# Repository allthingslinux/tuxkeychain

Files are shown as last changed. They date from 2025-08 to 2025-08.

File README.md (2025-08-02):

# Tux Keychain
Keychain shaped like Tux, the Linux mascot. But it's not just a keychain, it runs embedded Linux!

Unfortunately this is more expensive than usual due to tariffs and inflation. (Probably cheaper in other countries.)

NOTE: This is still in the prototype stage, changes to the design are likely.

## Manufacturing
- This is a 4-layer PCB so it can fit in the Tux keychain form factor.
- Make sure you use ENIG for the PCB finish, else Tux will be gray instead of gold. (If you want a gray Tux, seek help.)
- This is designed for JLCPCBs assembly service, some parts are LCSC exclusive*.

*You can probably find them on other chinese distributors, but I don't know which ones.

## Attribution
The Allwinner F1C100s footprint/symbol is from https://github.com/thirtythreeforty/3340_kicad (F1C100s symbol, QFN-88_EP_10x10_Pitch0.4mm footprint).
Same for the JW5211 symbol and footprint.

Schematic heavily based on the business card design by thirtythreeforty (https://www.thirtythreeforty.net/posts/2019/12/my-business-card-runs-linux/businesscard.pdf).

Tux attribution: [lewing@isc.tamu.edu](https://isc.tamu.edu/~lewing/linux/) (Larry Ewing) and [The GIMP](https://www.gimp.org/).

## Images
> [!NOTE]
> These are auto-generated and will always be up to date (GitHub cache may make them seem out of date)

|PCB|Schematic|
|---|---|
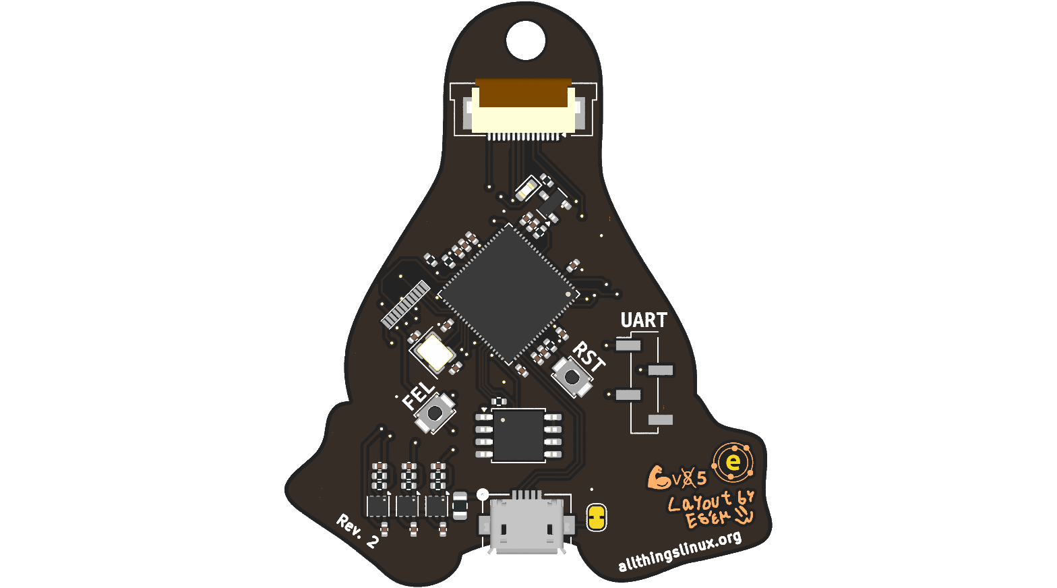
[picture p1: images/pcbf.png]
PCB Front
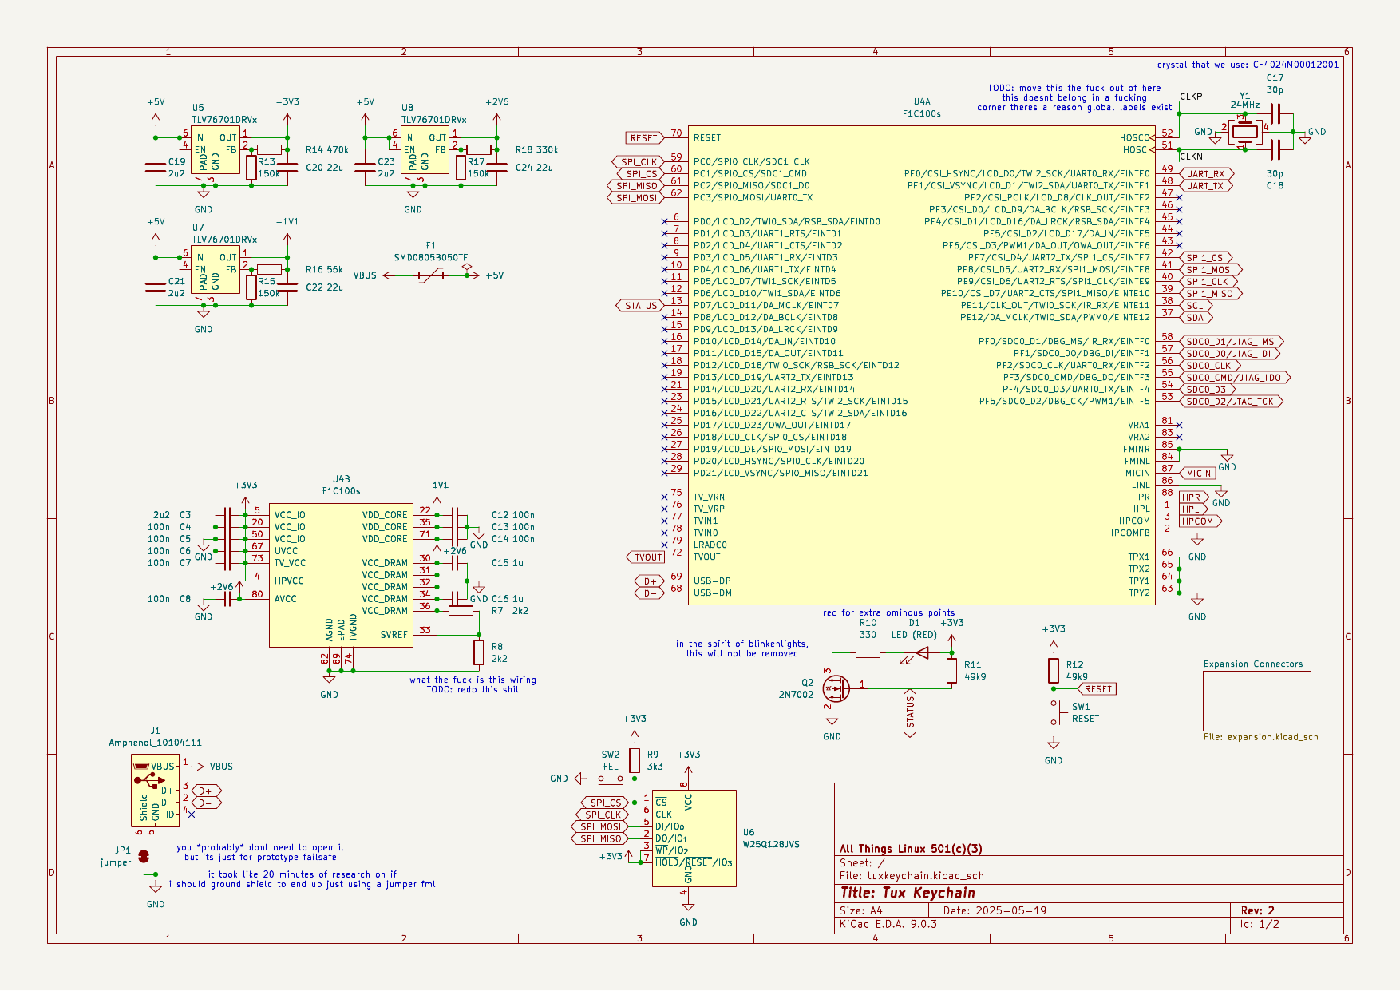
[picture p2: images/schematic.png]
Schematic
|||
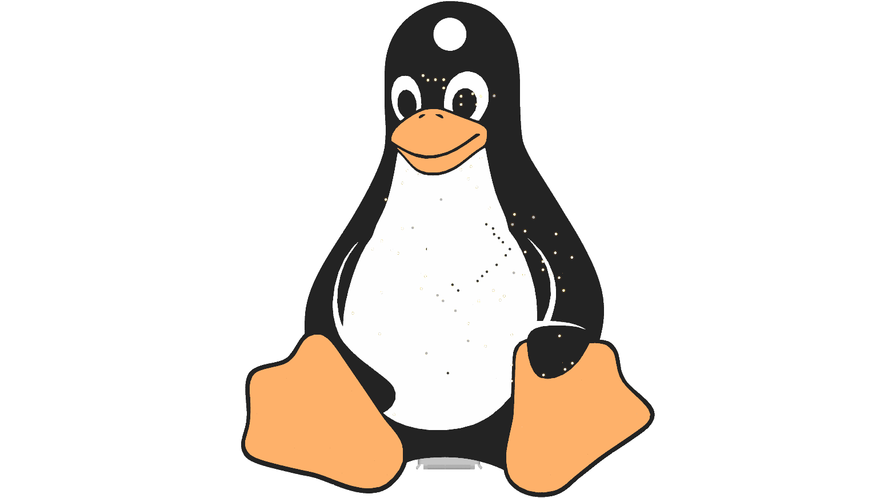
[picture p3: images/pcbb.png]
PCB Back
|||

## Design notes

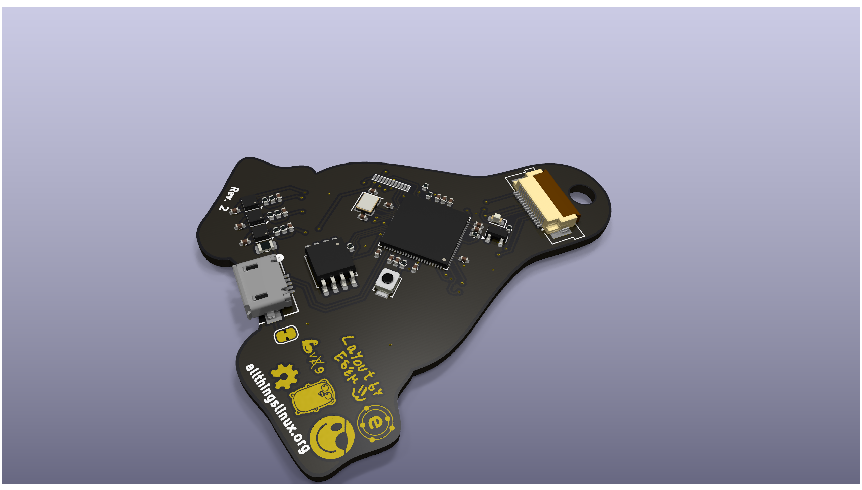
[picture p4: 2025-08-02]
tuxkeychain.png

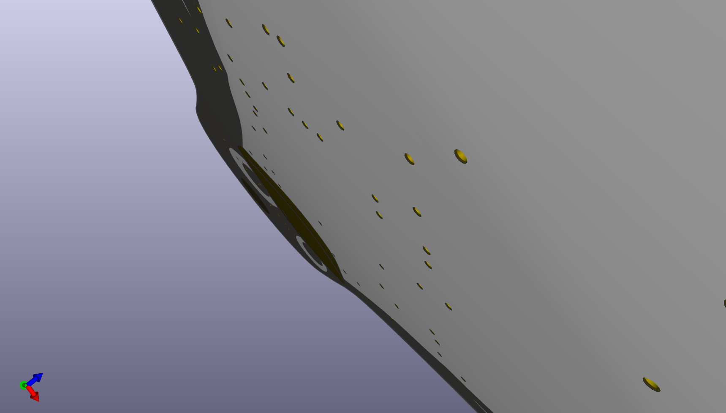
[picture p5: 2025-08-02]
tucks.png

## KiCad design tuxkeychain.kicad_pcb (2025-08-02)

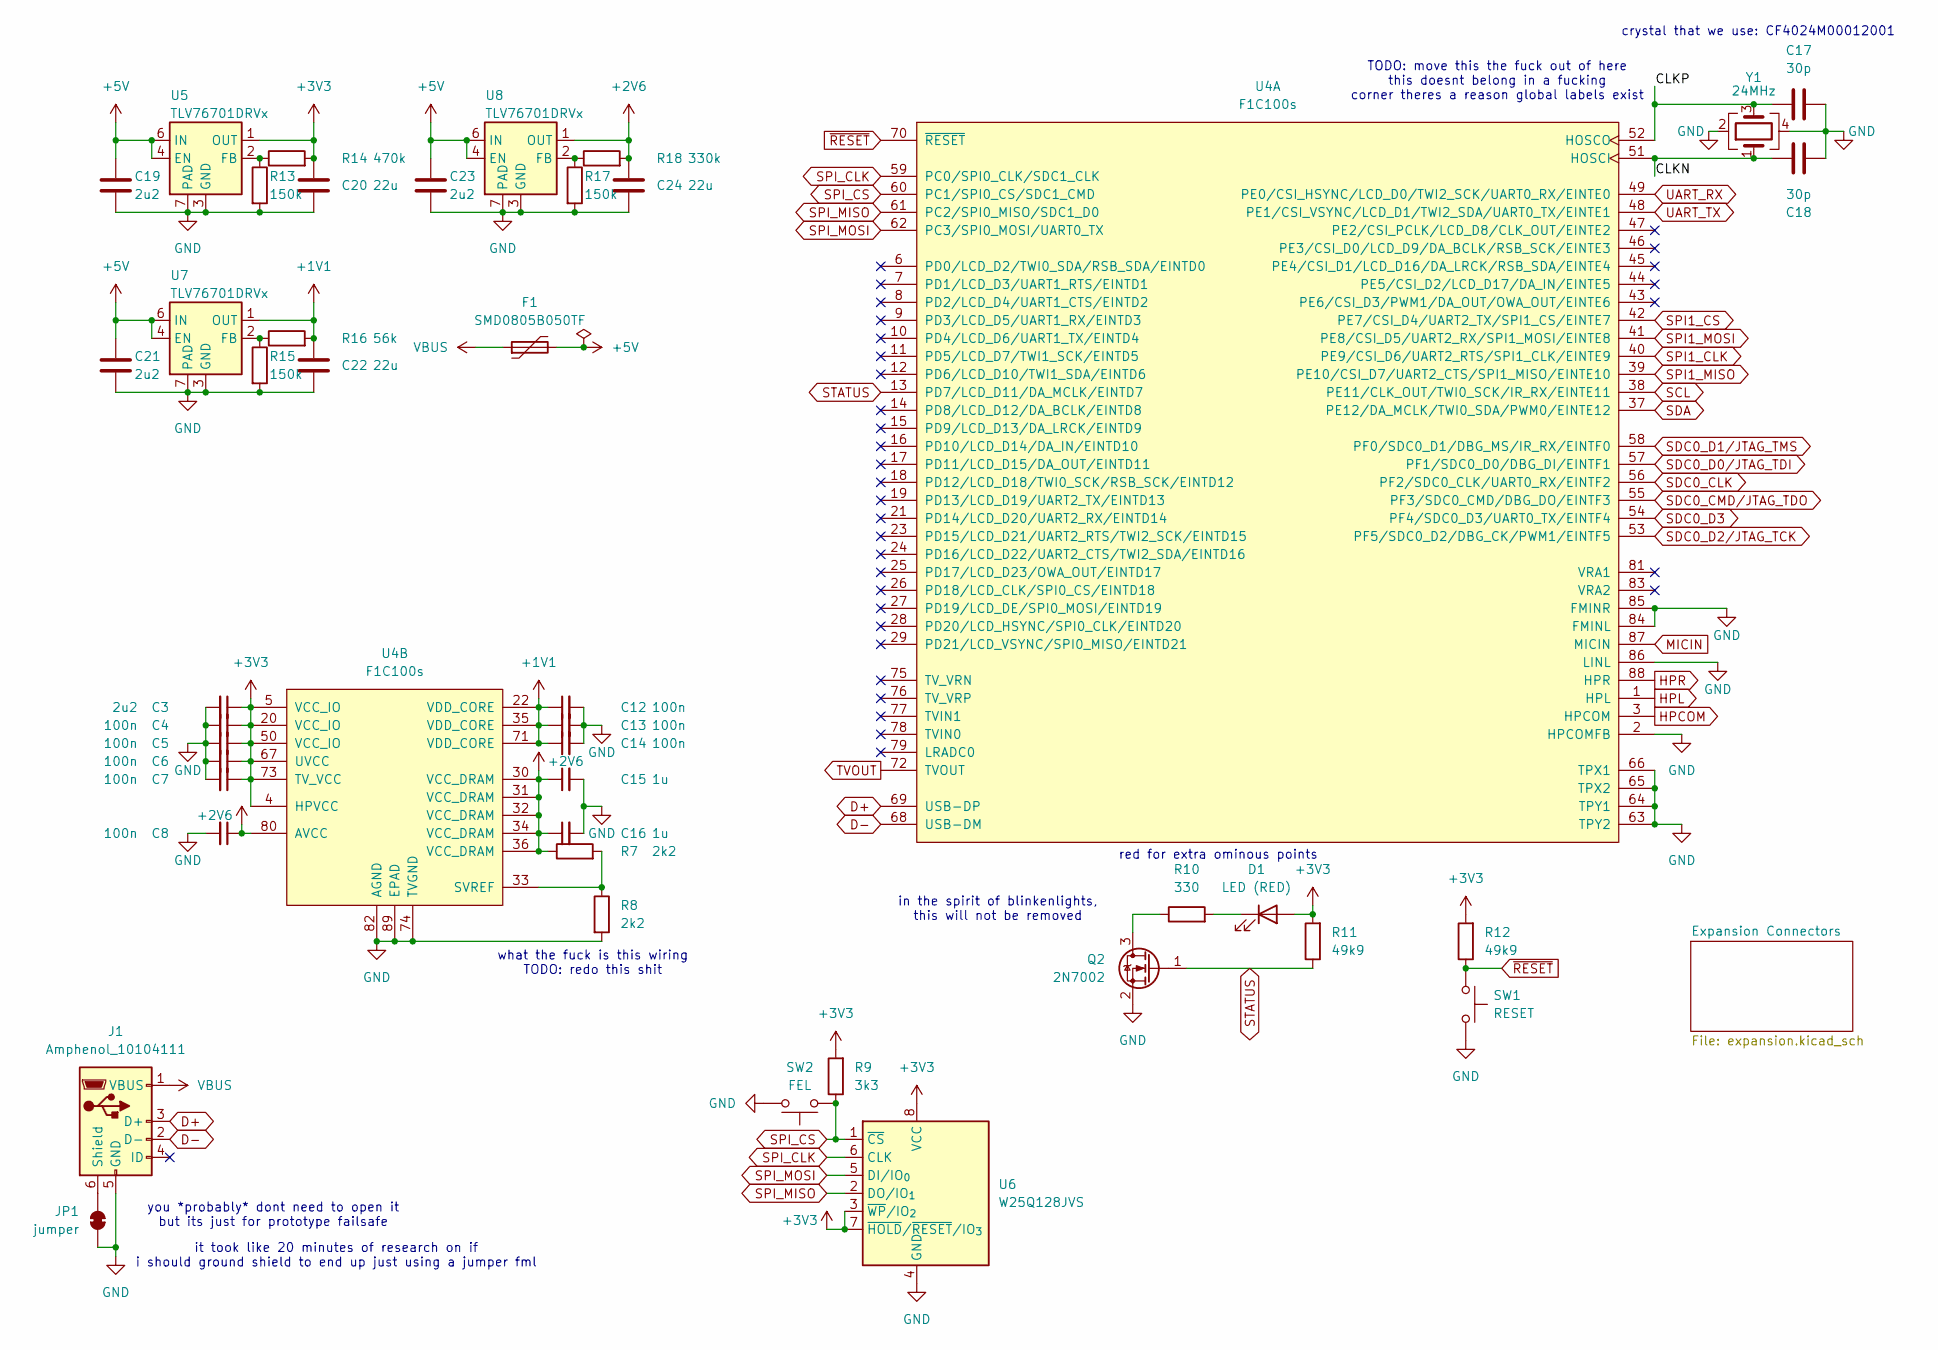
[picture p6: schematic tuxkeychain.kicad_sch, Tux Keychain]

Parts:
C3, C19, C21, C23: 2u2; C_0402_1005Metric
C4, C5, C6, C7, C8, C12, C13, C14: 100n; C_0402_1005Metric
C15, C16: 1u; C_0402_1005Metric
C17, C18: 30p; C_0402_1005Metric
C20, C22, C24: 22u; C_0402_1005Metric
D1: LED (RED); LED_0603_1608Metric
F1: SMD0805B050TF; Fuse_0805_2012Metric
J1: Amphenol_10104111; CONN_10104111-0001LF_AMP
JP1: jumper; SolderJumper-2_P1.3mm_Bridged_RoundedPad1.0x1.5mm
Q2: 2N7002; SOT-23
R7, R8: 2k2; R_0402_1005Metric
R9: 3k3; R_0402_1005Metric
R10: 330; R_0402_1005Metric
R11, R12: 49k9; R_0402_1005Metric
R13, R15, R17: 150k; R_0402_1005Metric
R14: 470k; R_0402_1005Metric
R16: 56k; R_0402_1005Metric
R18: 330k; R_0402_1005Metric
SW1: RESET; SW_SPST_B3U-1000P
SW2: FEL; SW_SPST_B3U-1000P
U4: F1C100s; QFN-88_EP_10x10_Pitch0.4mm
U5, U7, U8: TLV76701DRVx; WSON-6-1EP_2x2mm_P0.65mm_EP1x1.6mm
U6: W25Q128JVS; SOIC-8_5.3x5.3mm_P1.27mm
Y1: 24MHz; Crystal_SMD_3225-4Pin_3.2x2.5mm

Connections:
+1V1: C12.1, C13.1, C14.1, C22.1, R16.2, U4.22 (VDD_CORE), U4.35 (VDD_CORE), U4.71 (VDD_CORE), U7.1 (OUT); also elsewhere on the board
+2V6: C8.1, C15.1, C16.1, C24.1, R7.1, R18.2, U4.30 (VCC_DRAM), U4.31 (VCC_DRAM), U4.32 (VCC_DRAM), U4.34 (VCC_DRAM), U4.36 (VCC_DRAM), U4.80 (AVCC), U8.1 (OUT); also elsewhere on the board
+3V3: C3.1, C4.1, C5.1, C6.1, C7.1, C20.1, D1.2 (A), R9.2, R11.2, R12.2, R14.2, U4.4 (HPVCC), U4.5 (VCC_IO), U4.20 (VCC_IO), U4.50 (VCC_IO), U4.67 (UVCC), U4.73 (TV_VCC), U5.1 (OUT), U6.3 (~WP/IO_{2}), U6.7 (~HOLD/~RESET/IO_{3}), U6.8 (VCC); also elsewhere on the board
+5V: C19.1, C21.1, C23.1, F1.2, U5.4 (EN), U5.6 (IN), U7.4 (EN), U7.6 (IN), U8.4 (EN), U8.6 (IN); also elsewhere on the board
/CLKN: C18.1, U4.51 (HOSCI), Y1.1
/CLKP: C17.1, U4.52 (HOSCO), Y1.3
D+: J1.3 (D+), U4.69 (USB-DP)
D-: J1.2 (D-), U4.68 (USB-DM)
GND: C3.2, C4.2, C5.2, C6.2, C7.2, C8.2, C12.2, C13.2, C14.2, C15.2, C16.2, C17.2, C18.2, C19.2, C20.2, C21.2, C22.2, C23.2, C24.2, J1.5 (GND), JP1.1 (A), Q2.2 (S), R8.2, R13.2, R15.2, R17.2, SW1.2, SW2.2, U4.2 (HPCOMFB), U4.63 (TPY2), U4.64 (TPY1), U4.65 (TPX2), U4.66 (TPX1), U4.74 (TVGND), U4.82 (AGND), U4.84 (FMINL), U4.85 (FMINR), U4.86 (LINL), U4.89 (EPAD), U5.3 (GND), U5.5 (GND), U5.7 (PAD), U6.4 (GND), U7.3 (GND), U7.5 (GND), U7.7 (PAD), U8.3 (GND), U8.5 (GND), U8.7 (PAD), Y1.2, Y1.4; also elsewhere on the board
HPCOM: U4.3 (HPCOM); also elsewhere on the board
HPL: U4.1 (HPL); also elsewhere on the board
HPR: U4.88 (HPR); also elsewhere on the board
MICIN: U4.87 (MICIN); also elsewhere on the board
unnamed: D1.1 (K), R10.2
unnamed: J1.6 (Shield), JP1.2 (B)
unnamed: Q2.3 (D), R10.1
unnamed: R7.2, R8.1, U4.33 (SVREF)
unnamed: R13.1, R14.1, U5.2 (FB)
unnamed: R15.1, R16.1, U7.2 (FB)
unnamed: R17.1, R18.1, U8.2 (FB)
SCL: U4.38 (PE11/CLK_OUT/TWI0_SCK/IR_RX/EINTE11); also elsewhere on the board
SDA: U4.37 (PE12/DA_MCLK/TWI0_SDA/PWM0/EINTE12); also elsewhere on the board
SDC0_CLK: U4.56 (PF2/SDC0_CLK/UART0_RX/EINTF2); also elsewhere on the board
SDC0_CMD/JTAG_TDO: U4.55 (PF3/SDC0_CMD/DBG_DO/EINTF3); also elsewhere on the board
SDC0_D0/JTAG_TDI: U4.57 (PF1/SDC0_D0/DBG_DI/EINTF1); also elsewhere on the board
SDC0_D1/JTAG_TMS: U4.58 (PF0/SDC0_D1/DBG_MS/IR_RX/EINTF0); also elsewhere on the board
SDC0_D2/JTAG_TCK: U4.53 (PF5/SDC0_D2/DBG_CK/PWM1/EINTF5); also elsewhere on the board
SDC0_D3: U4.54 (PF4/SDC0_D3/UART0_TX/EINTF4); also elsewhere on the board
SPI1_CLK: U4.40 (PE9/CSI_D6/UART2_RTS/SPI1_CLK/EINTE9); also elsewhere on the board
SPI1_CS: U4.42 (PE7/CSI_D4/UART2_TX/SPI1_CS/EINTE7); also elsewhere on the board
SPI1_MISO: U4.39 (PE10/CSI_D7/UART2_CTS/SPI1_MISO/EINTE10); also elsewhere on the board
SPI1_MOSI: U4.41 (PE8/CSI_D5/UART2_RX/SPI1_MOSI/EINTE8); also elsewhere on the board
SPI_CLK: U4.59 (PC0/SPI0_CLK/SDC1_CLK), U6.6 (CLK)
SPI_CS: R9.1, SW2.1, U4.60 (PC1/SPI0_CS/SDC1_CMD), U6.1 (~CS)
SPI_MISO: U4.61 (PC2/SPI0_MISO/SDC1_D0), U6.2 (DO/IO_{1})
SPI_MOSI: U4.62 (PC3/SPI0_MOSI/UART0_TX), U6.5 (DI/IO_{0})
STATUS: Q2.1 (G), R11.1, U4.13 (PD7/LCD_D11/DA_MCLK/EINTD7)
TVOUT: U4.72 (TVOUT); also elsewhere on the board
UART_RX: U4.49 (PE0/CSI_HSYNC/LCD_D0/TWI2_SCK/UART0_RX/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); also elsewhere on the board
UART_TX: U4.48 (PE1/CSI_VSYNC/LCD_D1/TWI2_SDA/UART0_TX/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); also elsewhere on the board
VBUS: F1.1, J1.1 (VBUS)
~RESET: R12.1, SW1.1, U4.70 (~RESET)

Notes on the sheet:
red for extra ominous points
in the spirit of blinkenlights, this will not be removed
it took like 20 minutes of research on if i should ground shield to end up just using a jumper fml
crystal that we use: CF4024M00012001
you *probably* dont need to open it but its just for prototype failsafe
what the fuck is this wiring TODO: redo this shit
TODO: move this the fuck out of here this doesnt belong in a fucking corner theres a reason global labels exist

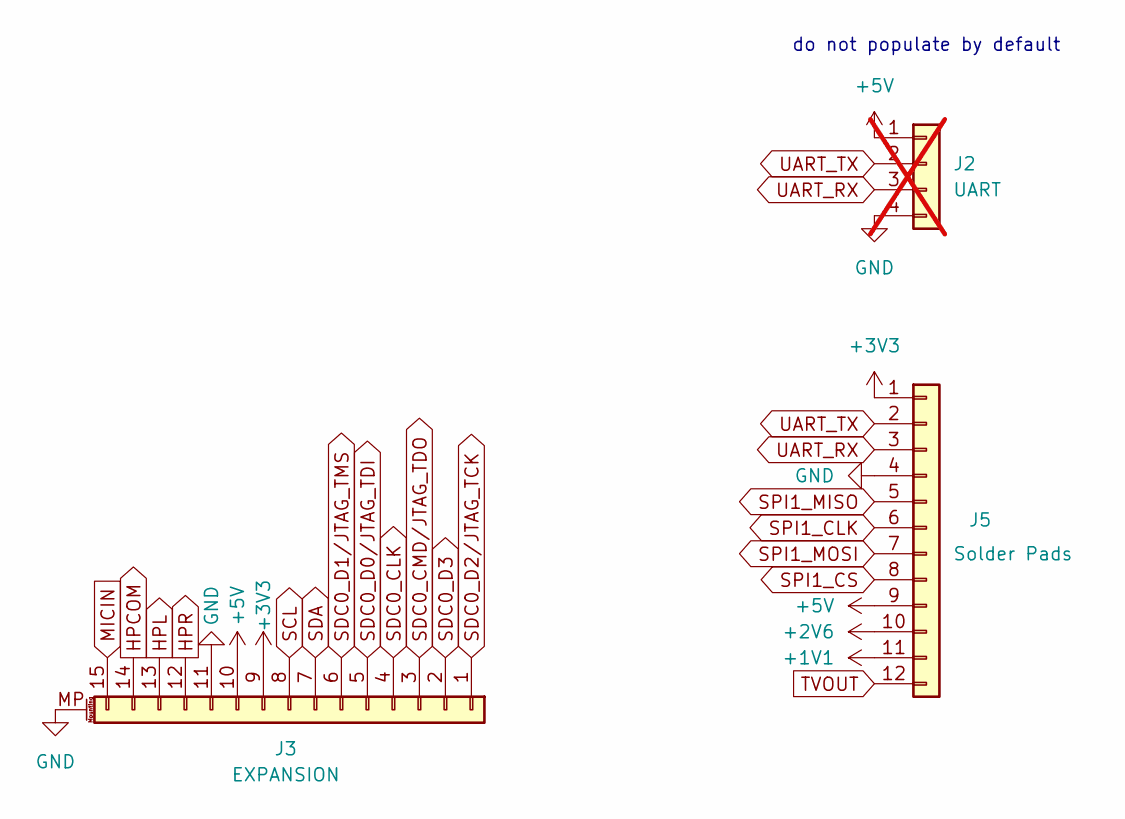
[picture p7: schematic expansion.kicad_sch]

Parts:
J2: UART; PinHeader_1x04_P2.54mm_Vertical_SMD_Pin1Left; not fitted
J3: EXPANSION; Jushuo_AFC07-S15FCA-00_1x15-1MP_P0.50_Horizontal
J5: Solder Pads; SolderPads12

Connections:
+1V1: J5.11; also elsewhere on the board
+2V6: J5.10; also elsewhere on the board
+3V3: J3.9, J5.1; also elsewhere on the board
+5V: J2.1, J3.10, J5.9; also elsewhere on the board
GND: J2.4, J3.11, J3.MP (MountPin), J5.4; also elsewhere on the board
HPCOM: J3.14; also elsewhere on the board
HPL: J3.13; also elsewhere on the board
HPR: J3.12; also elsewhere on the board
MICIN: J3.15; also elsewhere on the board
SCL: J3.8; also elsewhere on the board
SDA: J3.7; also elsewhere on the board
SDC0_CLK: J3.4; also elsewhere on the board
SDC0_CMD/JTAG_TDO: J3.3; also elsewhere on the board
SDC0_D0/JTAG_TDI: J3.5; also elsewhere on the board
SDC0_D1/JTAG_TMS: J3.6; also elsewhere on the board
SDC0_D2/JTAG_TCK: J3.1; also elsewhere on the board
SDC0_D3: J3.2; also elsewhere on the board
SPI1_CLK: J5.6; also elsewhere on the board
SPI1_CS: J5.8; also elsewhere on the board
SPI1_MISO: J5.5; also elsewhere on the board
SPI1_MOSI: J5.7; also elsewhere on the board
TVOUT: J5.12; also elsewhere on the board
UART_RX: J2.3, J5.3; also elsewhere on the board
UART_TX: J2.2, J5.2; also elsewhere on the board

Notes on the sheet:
do not populate by default

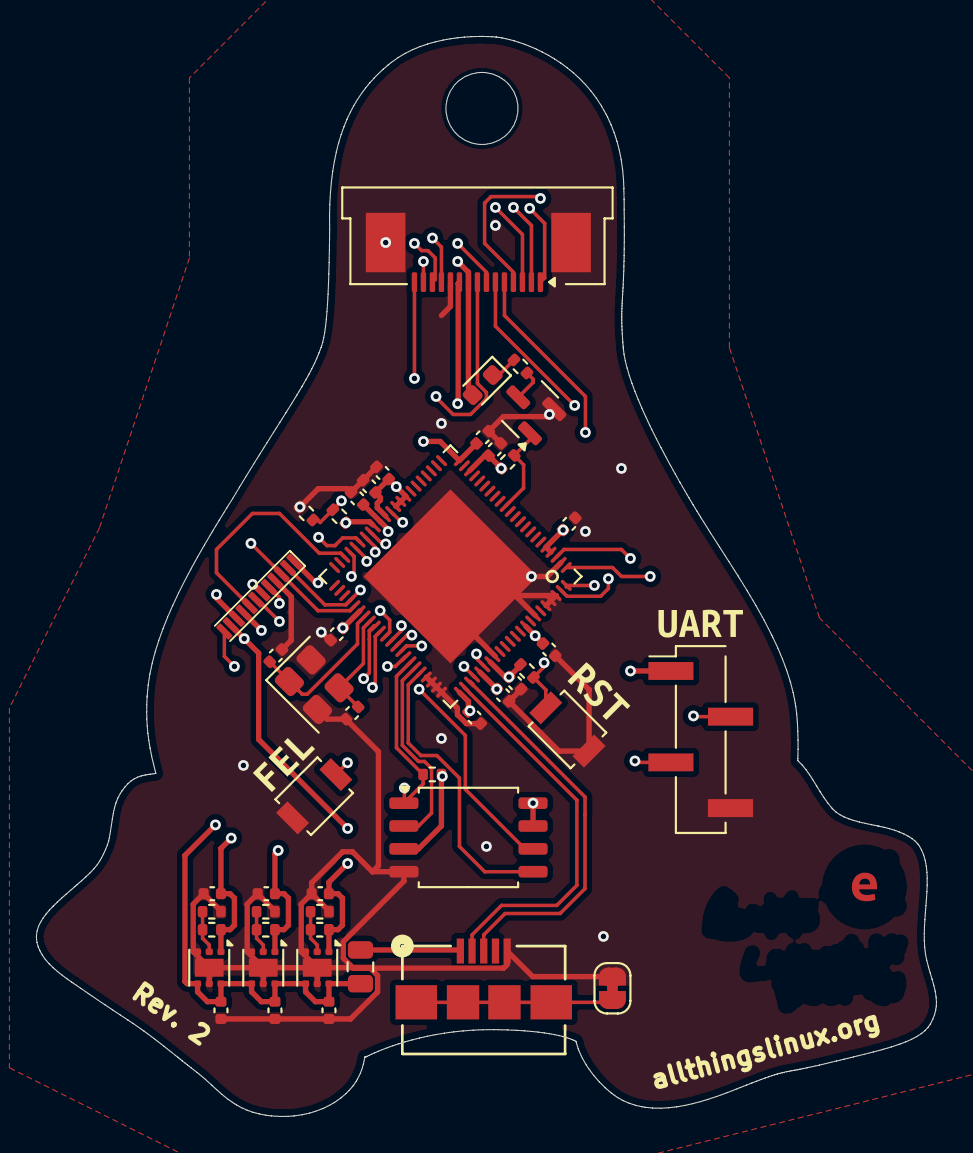
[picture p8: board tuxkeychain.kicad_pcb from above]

Board: 6 copper layers, 50.0 x 60.0 mm, 53 parts (3 on the bottom side), 42 nets.

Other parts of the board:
GRAPHIC1: DrillHole
GRAPHIC2, GRAPHIC3: Graphics
kibuzzard-687B569F: G***; kibuzzard-687B569F
kibuzzard-687B5666: G***; kibuzzard-687B5666
kibuzzard-688DDBDB: G***; kibuzzard-688DDBDB

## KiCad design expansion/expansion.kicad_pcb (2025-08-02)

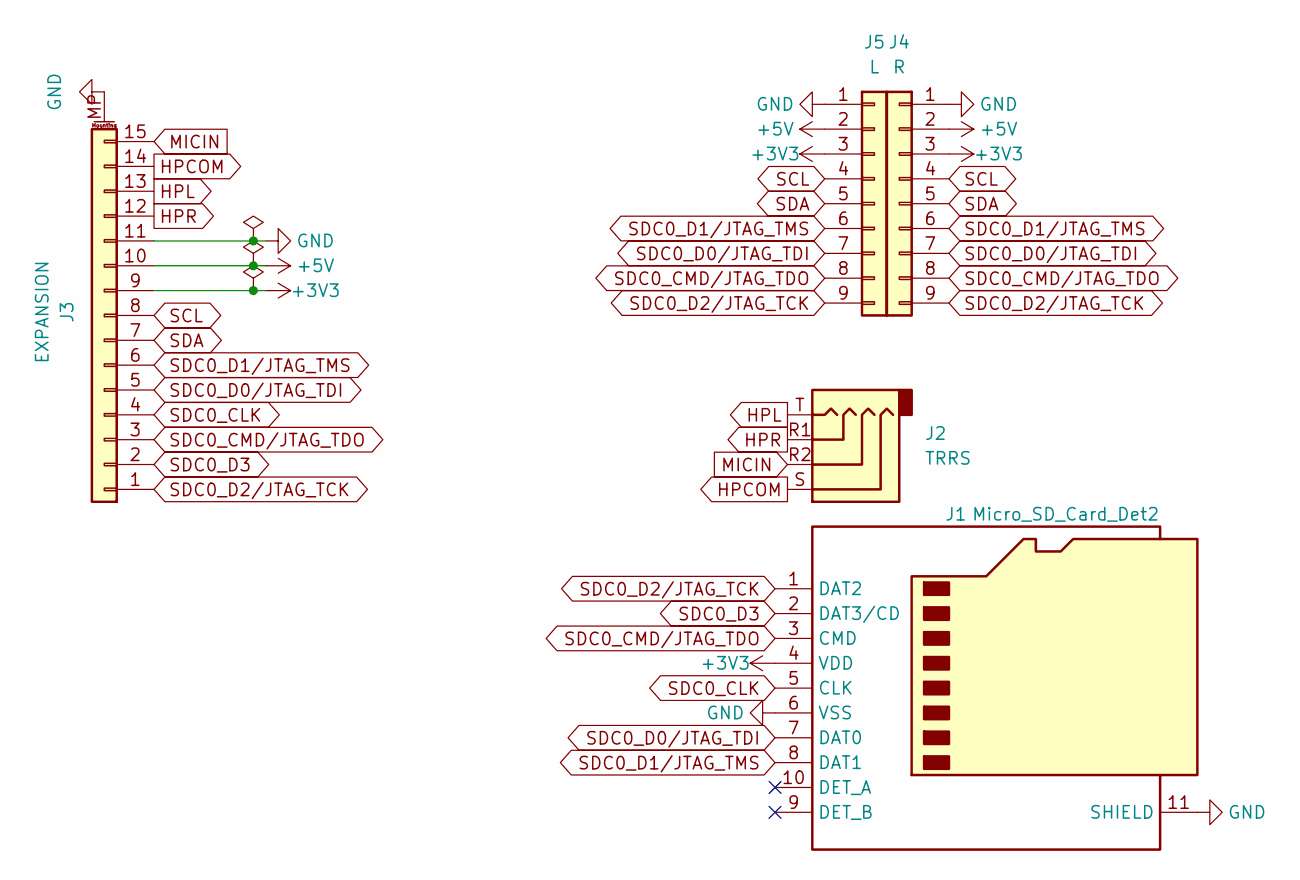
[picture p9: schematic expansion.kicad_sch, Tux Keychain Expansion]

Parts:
J1: Micro_SD_Card_Det2; microSD_HC_Molex_104031-0811
J2: TRRS; Jack_3.5mm_KoreanHropartsElec_PJ-320D-4A_Horizontal
J3: EXPANSION; FFC_1x15_P0.5mm
J4: R; PinHeader_1x09_P2.54mm_Vertical
J5: L; PinHeader_1x09_P2.54mm_Vertical

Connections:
+3V3: J1.4 (VDD), J3.9, J4.3, J5.3
+5V: J3.10, J4.2, J5.2
GND: J1.6 (VSS), J1.11 (SHIELD), J3.11, J3.MP (MountPin), J4.1, J5.1
HPCOM: J2.S, J3.14
HPL: J2.T, J3.13
HPR: J2.R1, J3.12
MICIN: J2.R2, J3.15
SCL: J3.8, J4.4, J5.4
SDA: J3.7, J4.5, J5.5
SDC0_CLK: J1.5 (CLK), J3.4
SDC0_CMD/JTAG_TDO: J1.3 (CMD), J3.3, J4.8, J5.8
SDC0_D0/JTAG_TDI: J1.7 (DAT0), J3.5, J4.7, J5.7
SDC0_D1/JTAG_TMS: J1.8 (DAT1), J3.6, J4.6, J5.6
SDC0_D2/JTAG_TCK: J1.1 (DAT2), J3.1, J4.9, J5.9
SDC0_D3: J1.2 (DAT3/CD), J3.2

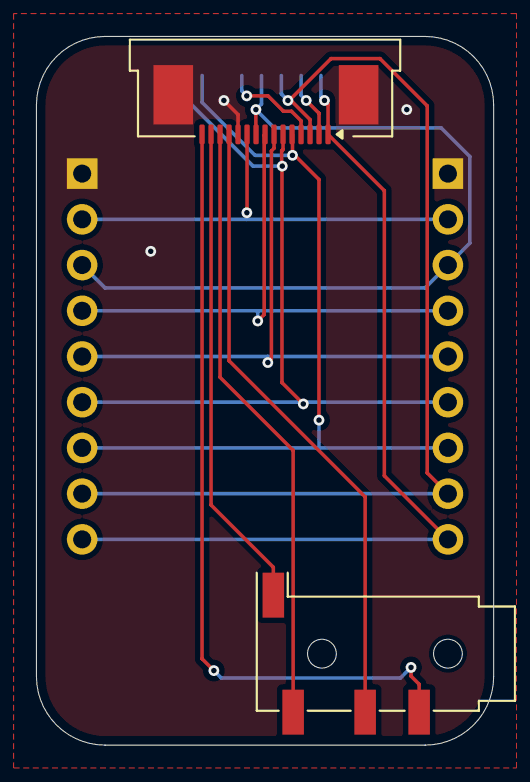
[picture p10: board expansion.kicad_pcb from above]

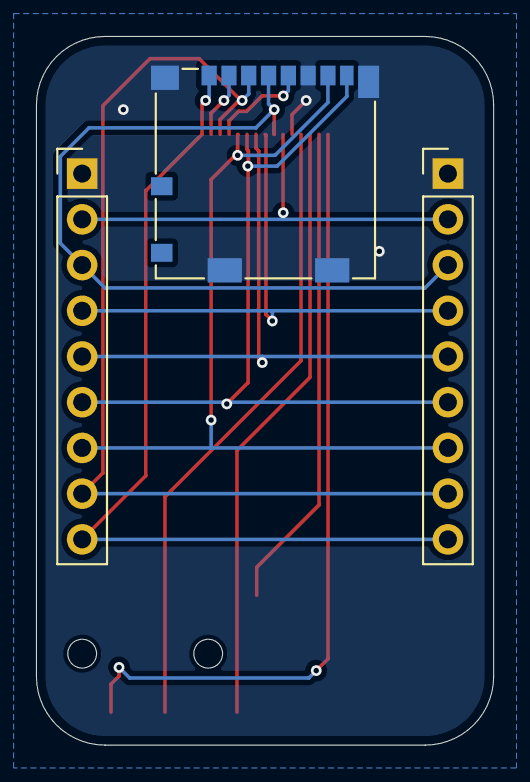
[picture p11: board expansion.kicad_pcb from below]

Board: 2 copper layers, 25.4 x 39.4 mm, 5 parts (3 on the bottom side), 15 nets.

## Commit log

2025-05-22 Change regulators to the TLV76701DRVx due to supply chain issues
    [tuxkeychain.kicad_sch]
2025-05-22 Refactor KiCad workflow to use cached APT packages for installation
2025-05-22 Revert "Refactor KiCad workflow to use cached APT packages for installation"
    This reverts commit 15d390258ad1cd0148efe828dac26ec40c4fc02e.
2025-05-22 Refactor KiCad CI workflow to use cache-apt-pkgs-action for package installation
2025-05-22 bump rev
    [tuxkeychain.kicad_sch]
2025-05-22 Revert "bump rev"
    This reverts commit ef9e417096638242890c258b05ee16d024b64b77.
    [tuxkeychain.kicad_sch]
2025-05-22 bump rev (this time correctly)
    [tuxkeychain.kicad_sch]
2025-05-22 Update resistor values in schematic to standard E12 values
    [tuxkeychain.kicad_sch]
2025-05-22 rev 2
    [tuxkeychain.kicad_pcb, tuxkeychain.kicad_sch]
2025-05-23 Added expansion connectors to schematic
    [expansion.kicad_sch, tuxkeychain.kicad_sch]
2025-05-23 Added expansion connectors to pcb
    [expansion.kicad_sch, tuxkeychain.kicad_pcb]
2025-05-23 more stuff
    [tuxkeychain.kicad_pcb]
2025-05-23 Fix installation issues in KiCad workflows
2025-05-23 full pbc layout completed
    [tuxkeychain.kicad_pcb]
2025-05-24 Update SolderPads12 footprint attributes to exclude from position files and BOM
2025-05-24 Changed board to 6 layers, made appropriate routing changes
    [tuxkeychain.kicad_pcb]
2025-05-25 minor trace cleanups
    [tuxkeychain.kicad_pcb]
2025-05-25 fix drc
    [tuxkeychain.kicad_pcb]
2025-05-25 fix name for footprint
    [expansion.kicad_sch, tuxkeychain.kicad_pcb]
2025-05-25 fix 3d model
    [tuxkeychain.kicad_pcb]
2025-05-25 remove some logos and re hide references
    [tuxkeychain.kicad_pcb]
2025-06-12 change led resistor and add FEL button
    [tuxkeychain.kicad_pcb, tuxkeychain.kicad_sch]
2025-07-19 add labels for the rst/fel buttons
    [tuxkeychain.kicad_pcb]
2025-07-19 change armv8 logo
    [tuxkeychain.kicad_pcb]
2025-08-02 add uart header
    [expansion.kicad_sch, tuxkeychain.kicad_pcb]
2025-08-02 fixed some wonky traces
    [tuxkeychain.kicad_pcb]
